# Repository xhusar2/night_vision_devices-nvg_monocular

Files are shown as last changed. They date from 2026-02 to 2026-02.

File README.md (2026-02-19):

# Night Vision Monocular Device

Night vision monocular – final product

## Intro

This project is a DIY night-vision monocular built from a RunCam Night Eagle 3 v2 analog camera and a small OLED display in a custom 3D‑printed housing. The case is designed to mount either on a head harness or on any Picatinny rail, making it usable as a helmet-mounted NVG or a simple rail-mounted viewer. It works with any IR torch or illuminator, is cheap and easy to assemble from off‑the‑shelf parts, and because the signal path is fully analog, latency is extremely low—so you can wear it for long periods without the motion sickness or headaches common with digital solutions.

## Features

- **Fully analog signal path** — No digital processing; minimal latency, no motion sickness from display lag.
- **Head harness or rail** — Use on a head strap or on any of the above mounts.
- **Adjustable brightness** — Buttons for brighter/dimmer display.
- **CNC aluminium camera housing** — Dissipates heat so the camera doesn't overheat or soften plastic.
- **Off-the-shelf parts** — RunCam + small display; easy to source and replace.
- support for multiple mounts
  - **Picatinny mount** — Optional piece that screws on for Picatinny rail (weapon, helmet rail, etc.).
  - **Wilcox dovetail shoe** — Adapter for Wilcox-style dovetail mounts (common on bump/ballistic helmets).
  - **J-arm mount** — Compatible with J-arm style NVG mounts.

## BOM

See [Bill of Materials](docs/BOM.md) for complete parts list.

## Build steps

1. Prepare the 3D printed parts
    - Insert all heat-inserts into the printed parts according to the model.
    - Make sure they sit flush and straight.
2. Thermal coupling
    - Apply thermal paste (or similar thermal interface material) onto the camera like in the image.
thermal paste
3. Mount the camera to the aluminium housing
    - Place the RunCam Night Eagle 3 v2 into the CNC aluminium camera housing.
camera in housing
    - Fix it in place using the two side screws.
housing screws
4. Solder the wiring
    - Solder the camera, display, buttons and power leads according to the wiring diagram.
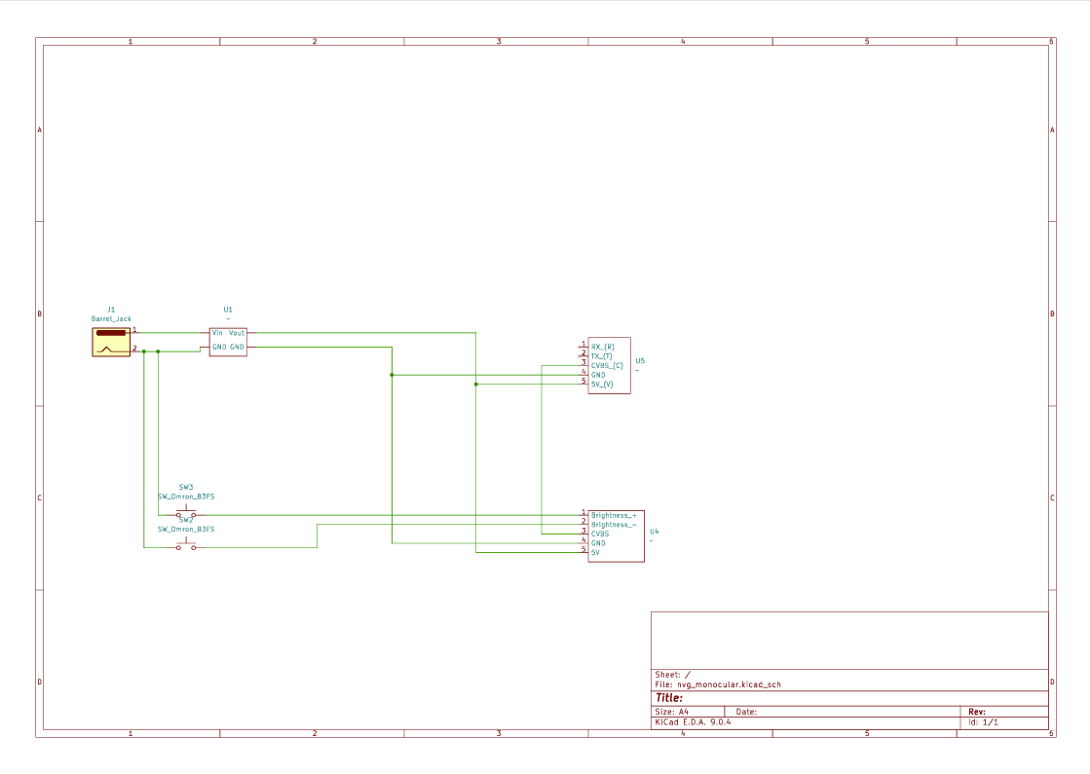
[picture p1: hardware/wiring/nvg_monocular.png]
wiring

5. Install electronics into the body
    - Slide wiring into the main body housing.
    - Route wires so they are not pinched and have basic strain relief.
6. Close the housing
    - Attach the aluminium camera housing to the main body with four screws.
housing
    - Verify the assembly is square and the camera is centered.
    - Verify the display and camera position are in line (you see the image as is, not flipped 90/180 degrees)
7. Install the optical lens
    - Connect the display to the camera
    - Install the display board in the slot on the image
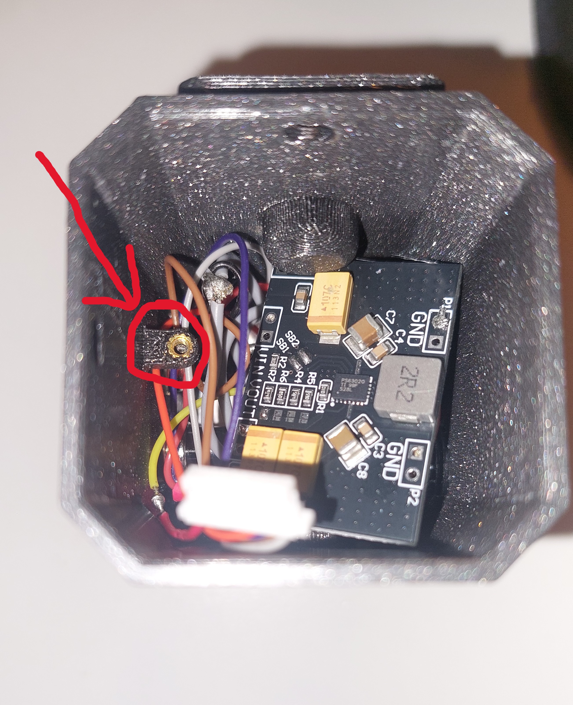
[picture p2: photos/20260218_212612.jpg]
housing

    - Insert the display part into the housing, and fasten with 2 screws (M3x6)
    - Adjust focus as needed. 
8. Power-up and basic test
    - Connect a stable 5 V power supply.
    - Verify the display shows the camera image and there is no flicker or noise.
9. Button and brightness check
    - Press the buttons to confirm they adjust display brightness (brighter/dimmer) as expected.
    - If needed, re-check wiring for the button lines.

## Troubleshooting

The camera itself can get quite hot to the touch, if encased in PLA, it can melt the casing after while. The solution for this is to make the housing from aluminium with CNC. Mount the camera in the aluminium case and use thermal paste to make contact with it for better heat trasfer.

## Future improvements

- Integrated power attachment
- Onboard recording using RunCam module and SD-card
- Weather sealing - gaskets and o-rings for outdoor abuse

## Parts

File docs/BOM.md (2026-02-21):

# Bill of Materials

| Item | Qty | Part / Model | Notes | Price | Link |
|---|-----|---|---|---|---|
| Analog night camera | 1 | RunCam Night Eagle 3 v2 (or compatible) | Main image sensor | ~1,078.91 CZK | [AliExpress](https://www.aliexpress.com/item/1005007097063187.html) |
| Viewfinder / display | 1 | 0.4" viewfinder with display | - | 3,670.00 CZK | [AliExpress](https://www.aliexpress.com/item/1005008682525341.html) |
| Micro pins | 1 set | 5-pin, 5 sets | Connectors for camera/display | 44 CZK | [AliExpress](https://www.aliexpress.com/item/1005008669994352.html) |
| Tactile buttons | 1 pack | PBS-110 NO Black, 20 pcs | Brightness / UI | 45 CZK | [AliExpress](https://www.aliexpress.com/item/1005008777027854.html) |
| DC power jack | 1 | 2-way 5.5×2.1 mm | Power input | 57 CZK | [AliExpress](https://www.aliexpress.com/item/1005006375580065.html) |
| Aluminium camera housing | 1 | Custom CNC part | See `hardware/3d_parts/nvg_camera_housing_aluminium.step` | ~1200 CZK | — |
| Main body (3D print) | 1 | From `hardware/3d_parts/` | Print in PETG recommended | 100 CZK | — |
| Heat-set inserts | as per CAD | M2/M4 brass | For threaded joints | 30 CZK | — |
| M2x8 Screws | 8 | M2 stainless | - | 20 CZK | — |
| M2x6 Screws | 3 | M2 stainless | - | 20 CZK | — |
| M3x6 Screws | 2 | M3 stainless | - | 20 CZK | — |
| Thermal paste | — | Generic TIM | Camera ↔ aluminium housing | 100 CZK | — |

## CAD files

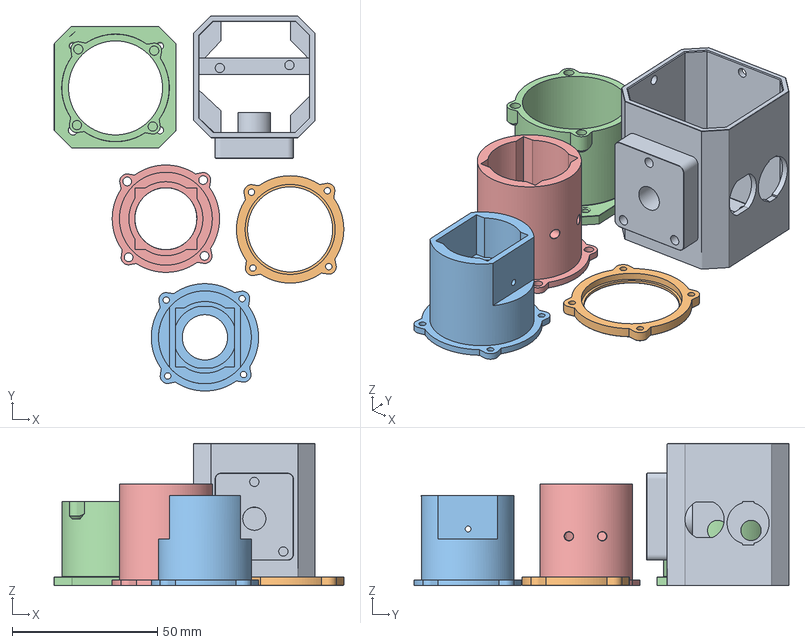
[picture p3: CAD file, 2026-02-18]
hardware/3d_parts/nvg_full_assembly.3mf
99.8 x 129.3 x 49.0 mm
Cover
Housing_night_eagle
Upper_box
thermal_housing

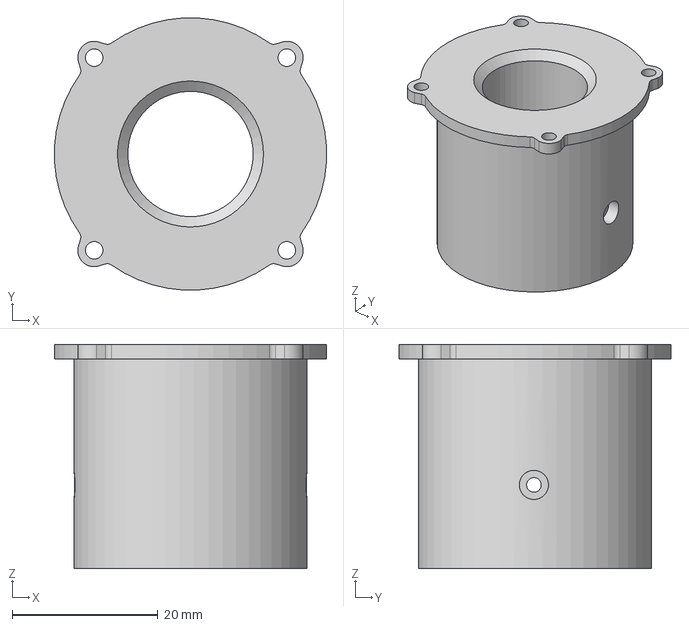
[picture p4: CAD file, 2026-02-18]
hardware/3d_parts/nvg_camera_housing_aluminium.step
37.3 x 37.3 x 30.8 mm

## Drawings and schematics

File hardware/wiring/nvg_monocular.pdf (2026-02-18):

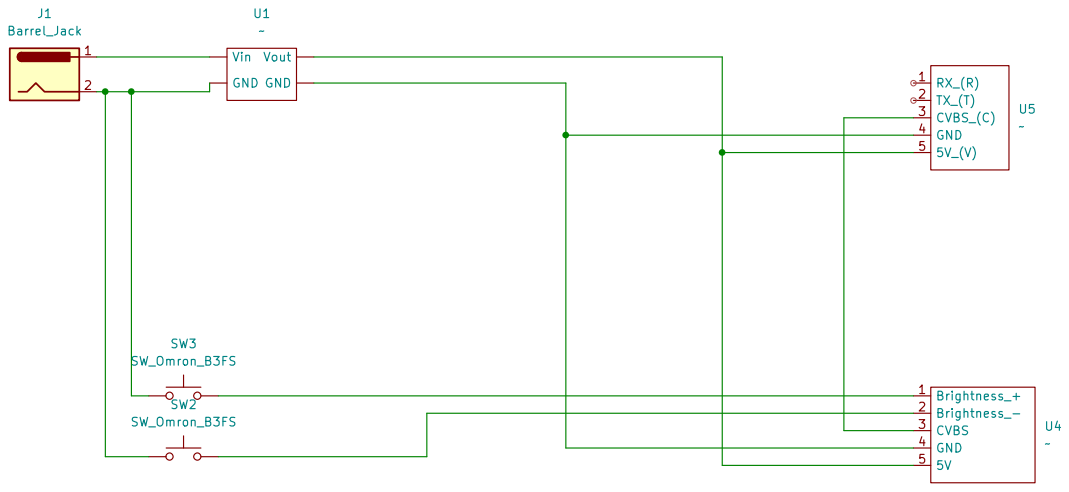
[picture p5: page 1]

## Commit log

2026-02-10 add assembly steps
2026-02-18 add 3d files
    [nvg_camera_housing_aluminium.step, nvg_full_assembly.3mf]
2026-02-18 add wiring
    [nvg_monocular.kicad_sch]
2026-02-18 write assembly part and crop photos
2026-02-19 rewrite BOM and readme
